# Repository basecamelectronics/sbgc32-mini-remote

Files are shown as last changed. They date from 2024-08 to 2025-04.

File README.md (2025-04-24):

Mini-Remote Controller Hardware
===============================
Web-site (https://www.basecamelectronics.com)

Description
-----------
This repository contains the main production files and other 3D files related to the MiniRemote project.

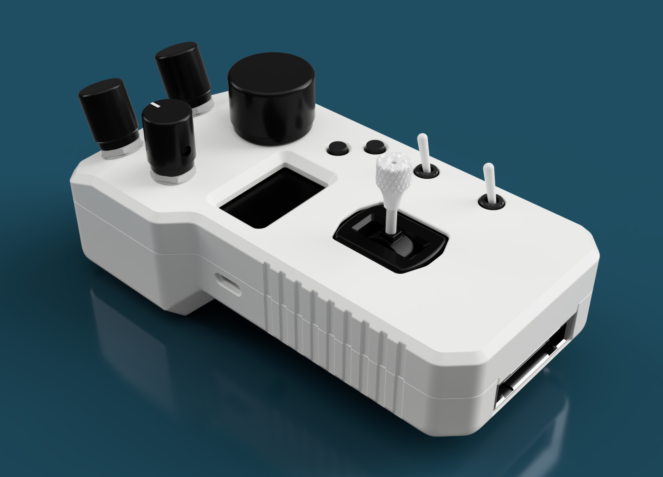
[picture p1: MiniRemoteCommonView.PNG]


The code for this device is also open-source. You can find it <a href="https://github.com/basecamelectronics/sbgc32-serial-api/tree/master/examples/STM32/MiniRemote">here</a></center>.
This folder contains a <a href="https://github.com/basecamelectronics/sbgc32-serial-api/tree/master/examples/STM32/MiniRemote/MiniRemoteDescription.pdf">document</a></center> with a more detailed description of the project.
This project will soon be available for order in our store.

Files Description
-----------------

[3D_Models/](3D_Models) - a folder with .step and .stl PCB 3D files;

[Enclosure/](Enclosure) - 3D models of the MiniRemote's casing and joysticks;

[PCB/](PCB) - the general manufacture files and sources;

[changelog.txt](changelog.txt) - a project changelog;

[MiniRemoteAccessories.csv](MiniRemoteAccessories.csv) - BOM for enclosure assembly;

[MiniRemoteAssemblyInstruction.pdf](MiniRemoteAssemblyInstruction.pdf) - Detailed assembly instructions.

Feedback
--------

If you have any questions or suggestions about using MiniRemote, you can contact at:

support@basecamelectronics.com

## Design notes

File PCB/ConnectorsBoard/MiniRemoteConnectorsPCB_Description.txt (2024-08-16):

MiniRemoteConnectorsPCB
=======================

Material: FR4
Dimension: 32x23mm
Layers: 2 (two)
PCB thickness: 1.6mm
Copper thickness: 35um
Solder mask: BLACK
Silkscreen: WHITE, top + bottom
Immersion gold plated

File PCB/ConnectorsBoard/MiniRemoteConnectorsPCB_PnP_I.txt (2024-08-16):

Altium Designer Pick and Place Locations
D:\basecam\MiniRemote\Project Outputs for MiniRemote\Pick Place\Generates pick and place files.txt

========================================================================================================================
File Design Information:

Date:       02.07.24
Time:       20:04
Revision:   Not in VersionControl
Variant:    No variations
Units used: mil

Designator Comment   Layer       Center-X(mil) Center-Y(mil) Rotation Description                                
P8         RS-422    TopLayer    976.772       598.032       180      "CONN RCPT FMALE 6POS GOLD SOLDER"         
P10        SerialAPI TopLayer    268.110       598.032       180      "CONN RCPT FMALE 4POS GOLD SOLDER"         
P7         LEMO_PCB  TopLayer    629.921       234.252       180      "WR-FPC 0.50 mm 10-pin SMT ZIF Horizontal" 
C31        100nF     BottomLayer 1010.000      375.002       0        "0603 100nF 50V X7R 10%"                   
C30        100nF     BottomLayer 614.998       450.000       90       "0603 100nF 50V X7R 10%"                   
C28        100nF     BottomLayer 399.998       583.032       90       "0603 100nF 50V X7R 10%"                   
C27        100nF     BottomLayer 539.998       450.000       90       "0603 100nF 50V X7R 10%"

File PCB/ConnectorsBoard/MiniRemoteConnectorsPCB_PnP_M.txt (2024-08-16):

Altium Designer Pick and Place Locations
D:\basecam\MiniRemote\Project Outputs for MiniRemote\Pick Place\Generates pick and place files.txt

========================================================================================================================
File Design Information:

Date:       02.07.24
Time:       20:05
Revision:   Not in VersionControl
Variant:    No variations
Units used: mm

Designator Comment   Layer       Center-X(mm) Center-Y(mm) Rotation Description                                
P8         RS-422    TopLayer    24.8100      15.1900      180      "CONN RCPT FMALE 6POS GOLD SOLDER"         
P10        SerialAPI TopLayer    6.8100       15.1900      180      "CONN RCPT FMALE 4POS GOLD SOLDER"         
P7         LEMO_PCB  TopLayer    16.0000      5.9500       180      "WR-FPC 0.50 mm 10-pin SMT ZIF Horizontal" 
C31        100nF     BottomLayer 25.6540      9.5251       0        "0603 100nF 50V X7R 10%"                   
C30        100nF     BottomLayer 15.6210      11.4300      90       "0603 100nF 50V X7R 10%"                   
C28        100nF     BottomLayer 10.1600      14.8090      90       "0603 100nF 50V X7R 10%"                   
C27        100nF     BottomLayer 13.7160      11.4300      90       "0603 100nF 50V X7R 10%"

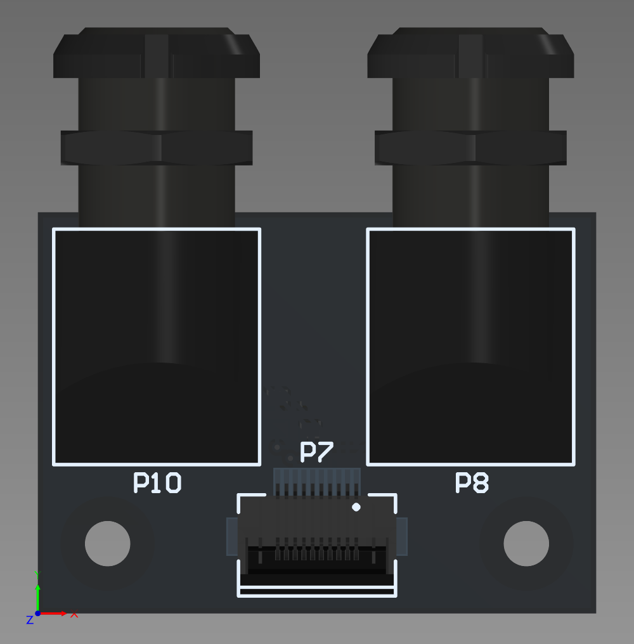
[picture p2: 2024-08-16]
PCB/ConnectorsBoard/MiniRemoteConnectorsMD_Top.png

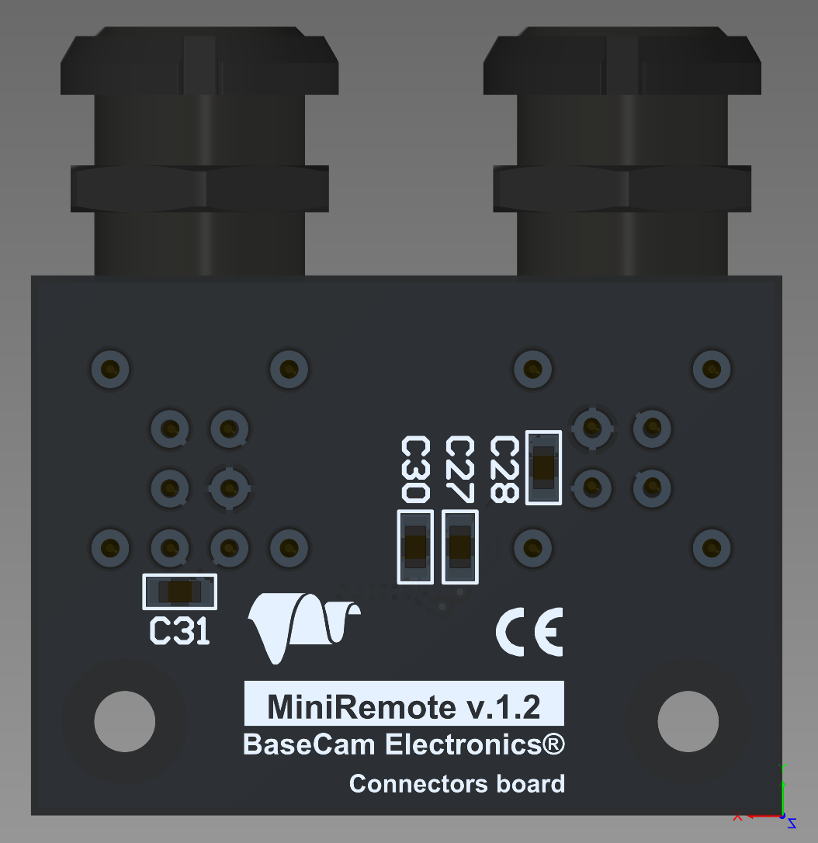
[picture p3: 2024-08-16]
PCB/ConnectorsBoard/MiniRemoteConnectorsMD_Bottom.png

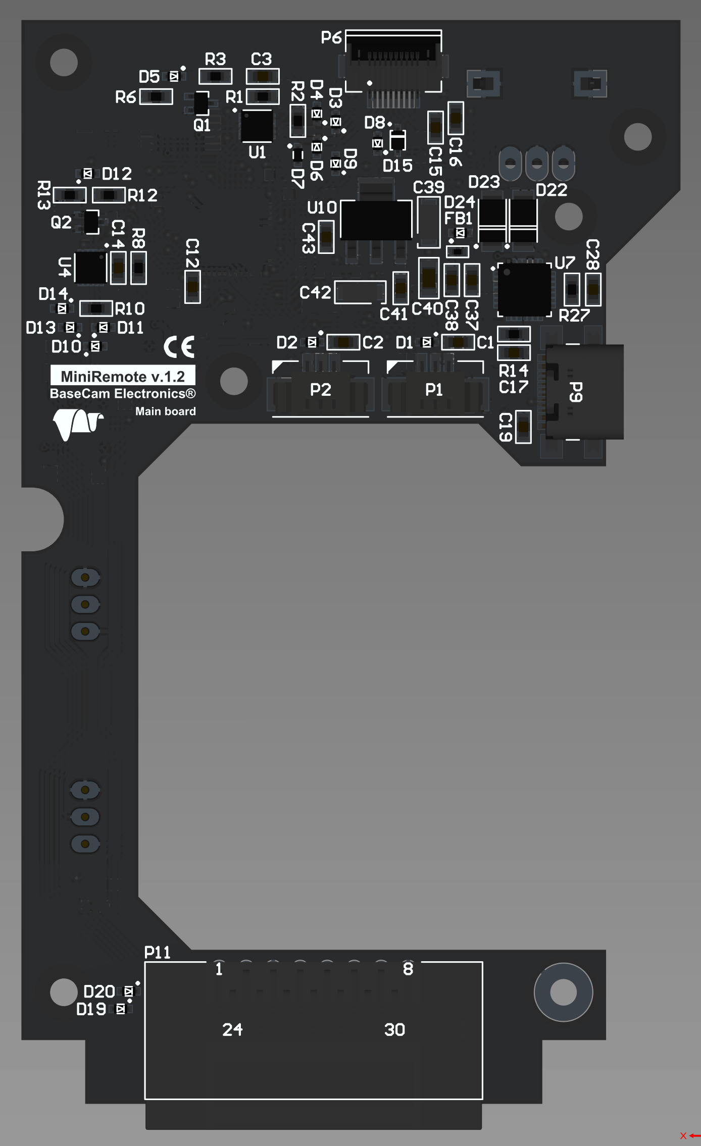
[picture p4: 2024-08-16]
PCB/MainBoard/MiniRemoteMainMD_Bottom.png

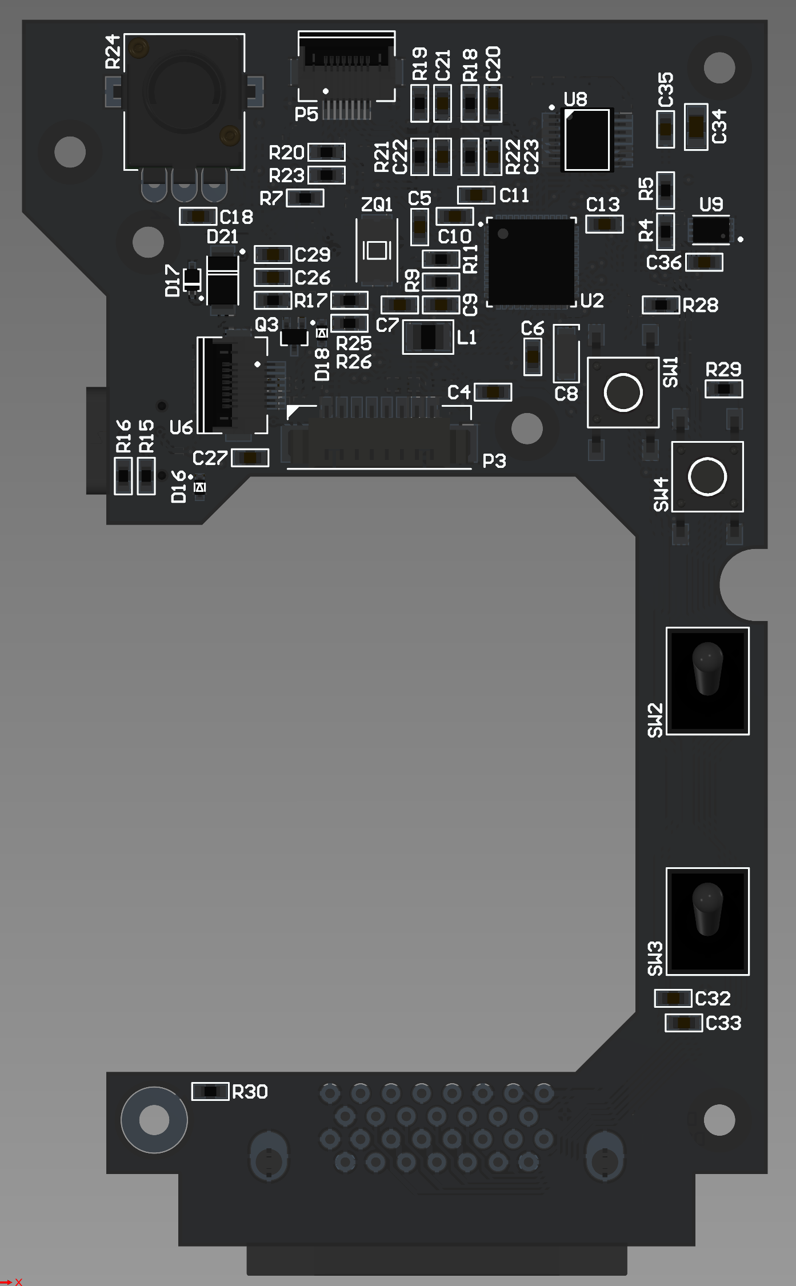
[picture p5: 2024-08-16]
PCB/MainBoard/MiniRemoteMainMD_Top.png

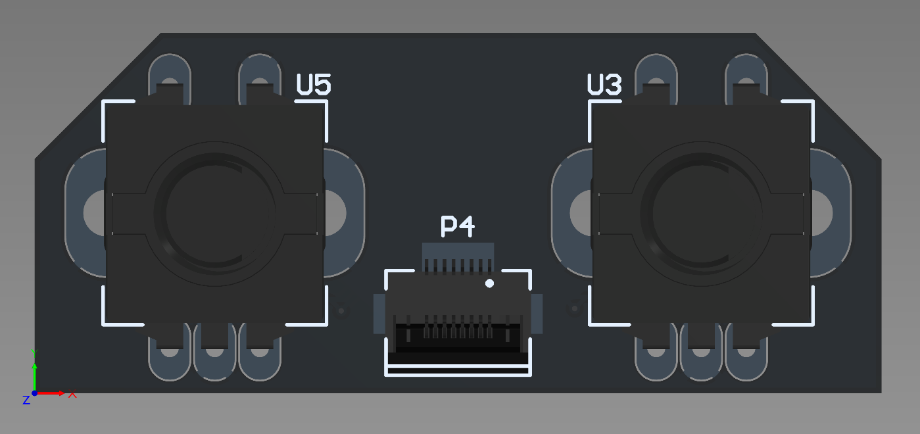
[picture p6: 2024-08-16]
PCB/EncodersBoard/MiniRemoteEncodersMD_Top.png

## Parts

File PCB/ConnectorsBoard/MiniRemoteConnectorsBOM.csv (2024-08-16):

Designator | Name | Value | Description | Quantity
C27, C28, C30, C31 |  | 100nF | 0603 100nF 50V X7R 10% | 4
P7 | 687110149022 |  | WR-FPC 0.50 mm 10-pin SMT ZIF Horizontal | 1
P8 | EXG.0B.306.HLN |  | CONN RCPT FMALE 6POS GOLD SOLDER | 1
P10 | EXG.0B.304.HLN |  | CONN RCPT FMALE 4POS GOLD SOLDER | 1

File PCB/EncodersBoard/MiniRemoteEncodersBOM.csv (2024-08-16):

Designator | Name | Value | Description | Quantity
P4 | 687108149022 |  | WR-FPC 0.50 mm 8-pin SMT ZIF Horizontal | 1
U3, U5 | PEC11L-4115F-S0020 |  | ROTARY ENCODER MECHANICAL 20PPR | 2

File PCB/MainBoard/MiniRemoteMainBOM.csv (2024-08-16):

Designator | Name | Value | Description | Quantity
C1, C2, C3, C4, C9, C10, C11, C12, C13, C14, C15, C16, C17, C19, C26, C27, C32, C33, C36, C38, C41, C43 |  | 100nF | 0603 100nF 50V X7R 10% | 22
C5, C7 |  | 8pF | 0603 8pF 50V C0G 5% | 2
C6, C29 |  | 2.2uF | 0603 2.2uF 10V X7R 10% | 2
C8 |  | 2.2uF | 1206 (A) 2.2uF 16V 10% | 1
C18, C20, C21, C22, C23, C28, C37 |  | 10nF | 0603 10nF 100V X7R 10% | 7
C34, C40 |  | 10uF | 0805 10uF 10V X5R 10% | 2
C35 |  | 1uF | 0603 1uF 10V X7R 10% | 1
C39 |  | 47uF | 1206 (A) 47uF 10V 20% | 1
C42 |  | 10uF | 1206 (A) 10uF 10V 10% | 1
D1, D2, D3, D4, D5, D6, D7, D10, D11, D12, D13, D14, D16, D18, D24 | ESD5B5.0ST1G |  | TVS DIODE 5VWM SOD523 | 15
D8, D9, D19, D20 | ESD3V3D5 |  | TVS DIODE 3.3VWM SOD523 | 4
D15, D17 | BAT760 |  | DIODE SCHOTTKY 20V 1A SOD323 | 2
D21, D22, D23 | PMEG3030BEP,115 |  | DIODE SCHOTTKY 30V 3A SOD128 | 3
FB1 | EPZ1005E221-1R2T |  | 0402 220 OHM 1LN | 1
L1 |  | 3.3uH | 1008 3.3uH 1.2A 100m OHM | 1
P1, P2 | 10114830-10103LF |  | CONN HEADER SMD R/A 3POS 1.25MM | 2
P3 | 0532610871 |  | CONN HEADER SMD R/A 8POS 1.25MM | 1
P5 | 687108149022 |  | WR-FPC 0.50 mm 8-pin SMT ZIF Horizontal | 1
P6 | 687110149022 |  | WR-FPC 0.50 mm 10-pin SMT ZIF Horizontal | 1
P9 | USB4110-GF-A |  | CONN RCP USB2.0 TYP C 24P SMD RA | 1
P11 | TX25-30P-LT-H1E |  | CONN PLUG 30POS R/A GOLD | 1
Q1, Q2 | BSS816NW |  | MOSFET N-CH 20V 1.4A SOT323-3 | 2
Q3 | NTS4101PT1G |  | MOSFET P-CH 20V 1.37A SC70-3 | 1
R1, R7, R8, R9, R18, R19, R20, R21, R22, R23, R28, R29 |  | 10K | 0603 10K OHM 0.1W 1% | 12
R2, R10 |  | 120 | 0603 120 OHM 0.1W 1% | 2
R3, R12, R26 |  | 510 | 0603 510 OHM 0.1W 1% | 3
R4, R5 |  | 2.4K | 0603 2.4K OHM 0.1W 1% | 2
R6, R13, R25 |  | 47K | 0603 47K OHM 0.1W 1% | 3
R11 |  | 1K | 0603 1K OHM 0.1W 1% | 1
R14 |  | 4.7K | 0603 4.7K OHM 0.1W 5% | 1
R15, R16 |  | 5.1K | 0603 5.1K OHM 0.1W 1% | 2
R17 |  | 180 | 0603 180 OHM 0.1W 1% | 1
R24 | P0915N-FC15BR100K | 100K | POT 100K OHM 0.05W 20% | 1
R27 |  | 1M | 0603 1M OHM 0.1W 1% | 1
R30 |  | 0 | 0603 0 OHM 0.1W | 1
SW1, SW4 | TL3301SPF260QG |  | SWITCH TACTILE SPST-NO 0.05A 12V | 2
SW2 | B13AP |  | SWITCH TOGGLE SPDT 0.4VA 28V | 1
SW3 | B18AP |  | SWITCH TOGGLE SPDT 0.4VA 28V | 1
U1, U4 | LTC2864HDD-1#PBF |  | 20Mbps and Slew Rate Limited 15kV RS485/RS422 Transceiver | 2
U2 | STM32F411CEU6 |  | IC MCU 32BIT 512KB FLSH 48UFQFPN | 1
U6 | 687108149022 |  | WR-FPC 0.50 mm 8-pin SMT ZIF Horizontal | 1
U7 | CP2102 |  | Single-Chip USB to UART Data Transfer | 1
U8 | AS5048B |  | Magnetic Rotary Encoder | 1
U9 | CAT24C256 |  | Two-Wire I2C Serial EEPROM | 1
U10 | LM1117MPX-3.3 |  | 800-mA, Low-Dropout Linear Regulator | 1
ZQ1 | NX5032GA | 8 MHz | CRYSTAL 8.0000MHZ 8PF SMD | 1

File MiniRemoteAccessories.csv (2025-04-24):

Name | Quantity | Link | ÿ
Knobs
OEJNI-90-4-7 - Abs.enc. | 1 | https://www.digikey.com/en/products/detail/kilo-international/OEJL-90-4-7/710686
OEJL-50-4-5 - Pot. | 1 | https://www.digikey.com/en/products/detail/kilo-international/OEJL-50-4-5/710642
OEJNI-50-4-7 - Encs. | 2 | https://www.digikey.com/en/products/detail/kilo-international/OEJL-50-4-7/710650
1RBLK - Buttons | 2 | https://www.digikey.com/en/products/detail/e-switch/1RBLK/271579
Cables
FFC 10-pin 0.5mm L30mm B-dir | 1 | https://www.aliexpress.com/item/1005004583056284.html
FFC 8-pin 0.5mm L30mm A-dir | 1 | https://www.aliexpress.com/item/1005004583043404.html
FGG.0B.306 + cable 3m | 1 | https://www.aliexpress.com/item/32716755431.html
FGG.0B.304 + cable 1m | 1 | https://www.aliexpress.com/item/32716755431.html
Assembly encoder
Bearing M6x12x4 | 1 | https://www.aliexpress.com/item/1005004692070656.html
Oil seal M6x12x3 | 1 | https://www.aliexpress.com/item/1005002594687400.html
Pillow M6x22 | 1 | https://www.aliexpress.com/item/1005006371763253.html
Nylon washer M6x12x0.5 | 2 | https://www.aliexpress.com/item/1005005893035927.html
Magnet M6x3 | 1 | https://www.aliexpress.com/item/1005002848356452.html
3D Body Pillow Joint | 1
Assembly display
3D Body Display Stand | 1
LCD TFT 135x240 1.14 inch | 1 | https://www.aliexpress.com/item/1005003772191934.html
Brass pillow M2.5x4 | 2 | https://www.aliexpress.com/item/1005002952338852.html
Screws PH1 M2.5x6 | 2
Nuts M2.5 | 2
Assembly case
3D Body Top | 1
3D Body Bottom | 1
Screws PH1 M2.5x16 - Top-Bottom | 6
Screws PH1 M2.5x6 - PCB-Bottom | 4
Screws PH1 M2x4 - Joystick-Top | 4
M12 Light Joystick | 1 | https://www.aliexpress.com/item/4001243553801.html

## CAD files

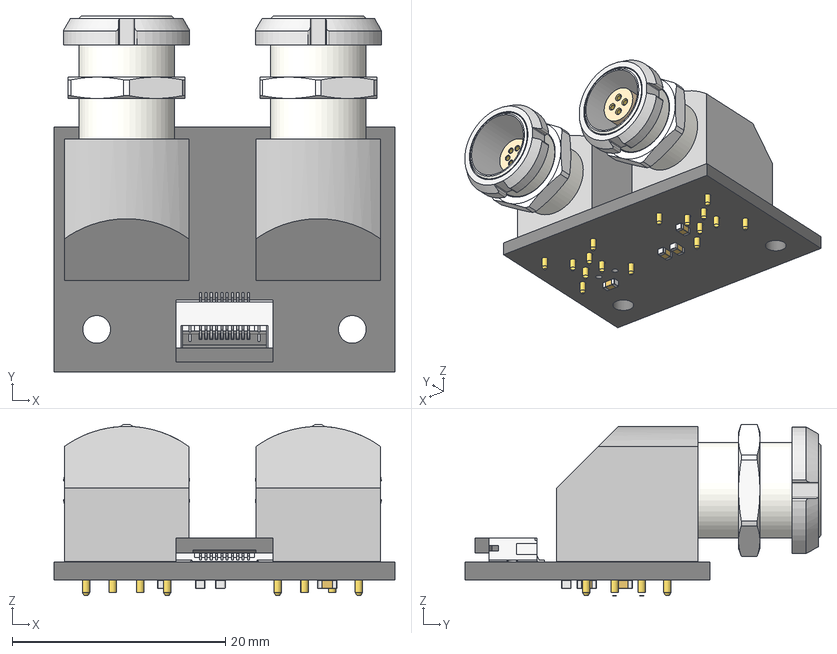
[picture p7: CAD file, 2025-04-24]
3D_Models/MiniRemoteConnectorsPCB.step
32.0 x 33.4 x 16.1 mm
EXG_0B_306_HLN
EXG_0B_304_HLN
6871xx149022_Pin x 10
6871xx149022_Patte
6871xx149022_Patte2
687110149022_Actuator

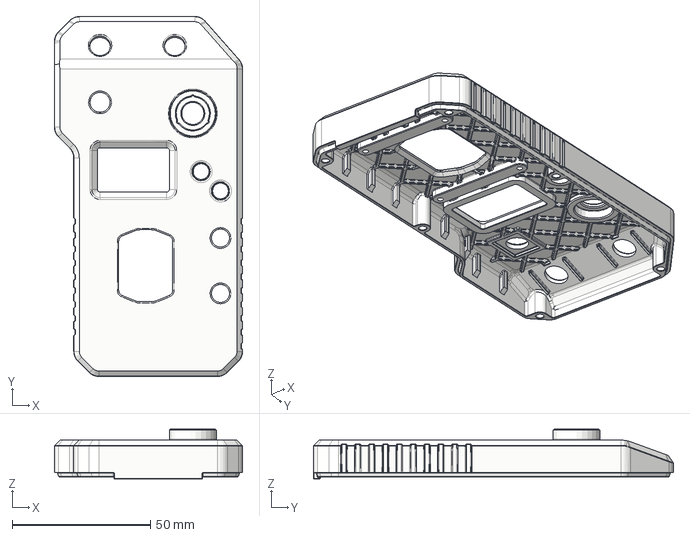
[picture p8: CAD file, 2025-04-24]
Enclosure/MiniRemoteBodyTop.step
68.0 x 130.0 x 18.0 mm

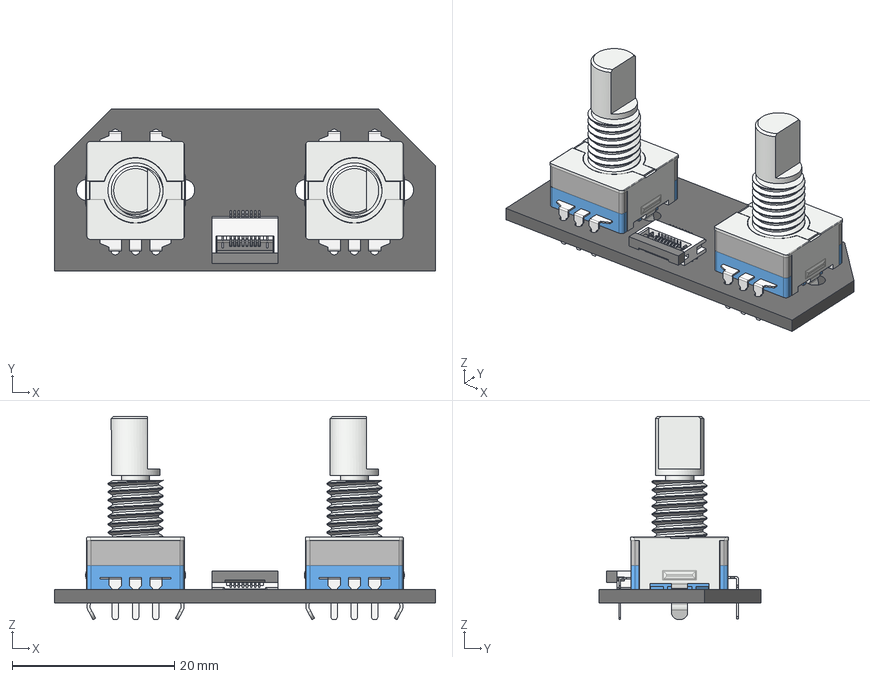
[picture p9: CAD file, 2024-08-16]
3D_Models/MiniRemoteEncodersPCB.step
47.0 x 20.0 x 25.1 mm
EC11-THT-Shaft_15MM_Blue x 2
6871xx149022_Pin x 8
6871xx149022_Patte
6871xx149022_Patte2
687108149022_Actuator

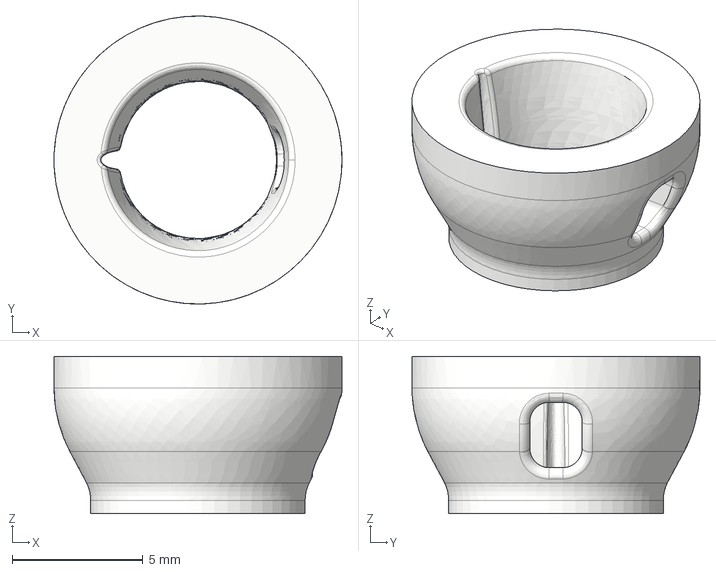
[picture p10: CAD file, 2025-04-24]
Enclosure/MiniRemoteEncoderPillowJoint.step
11.0 x 11.0 x 6.00 mm

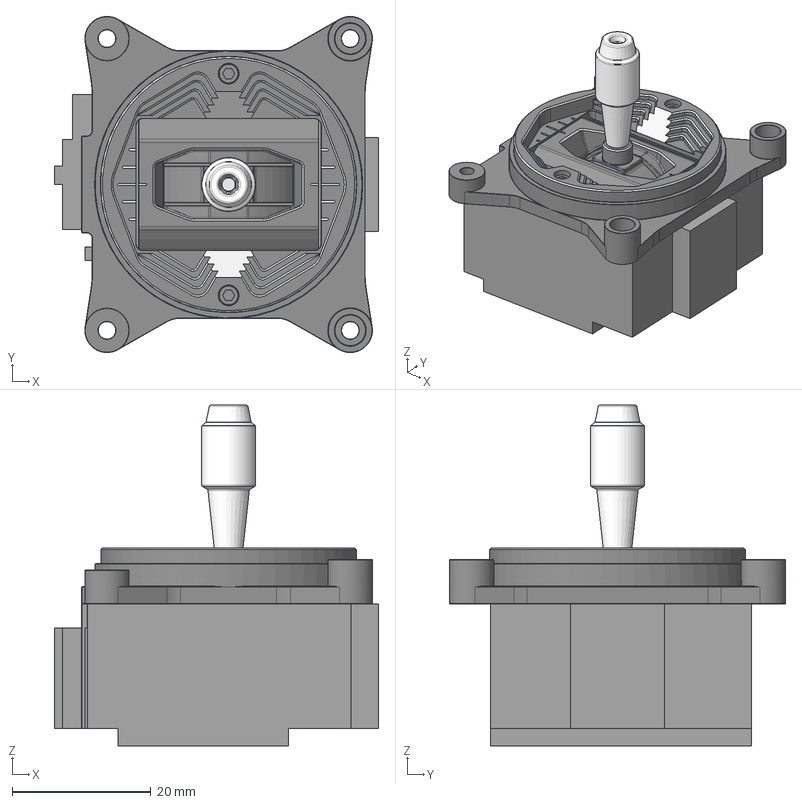
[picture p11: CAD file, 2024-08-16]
Enclosure/AG01 MINI CNC Hall Gimbals for TX12 & Zorro.step
46.8 x 48.5 x 49.2 mm

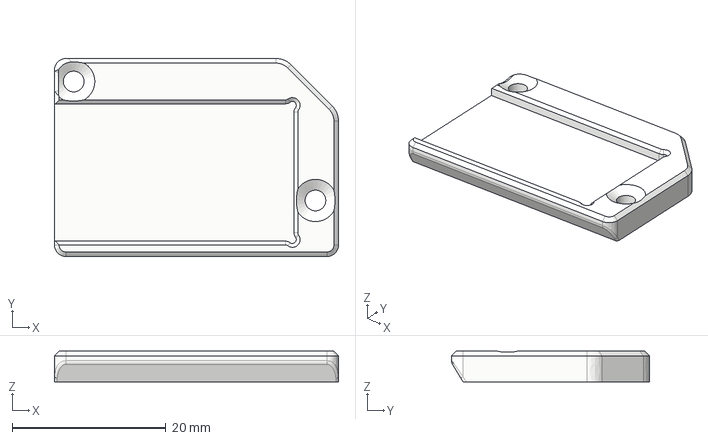
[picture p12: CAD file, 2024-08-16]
Enclosure/MiniRemoteDisplayStand.step
37.0 x 25.8 x 4.00 mm

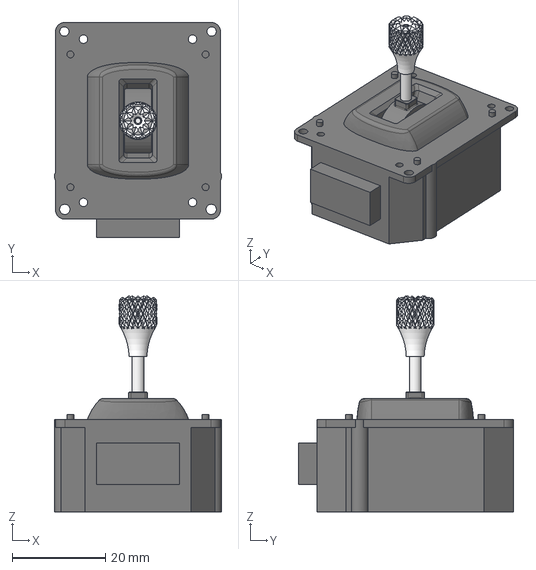
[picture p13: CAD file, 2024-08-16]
Enclosure/X-LiteProStick.step
35.8 x 46.2 x 46.3 mm

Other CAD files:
3D_Models/MiniRemoteConnectorsPCB.stl
3D_Models/MiniRemoteEncodersPCB.stl
Enclosure/MiniRemoteBodyTop.stl
Enclosure/MiniRemoteDisplayStand.stl

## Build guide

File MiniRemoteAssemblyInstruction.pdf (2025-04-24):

# MiniRemote assembly instruction

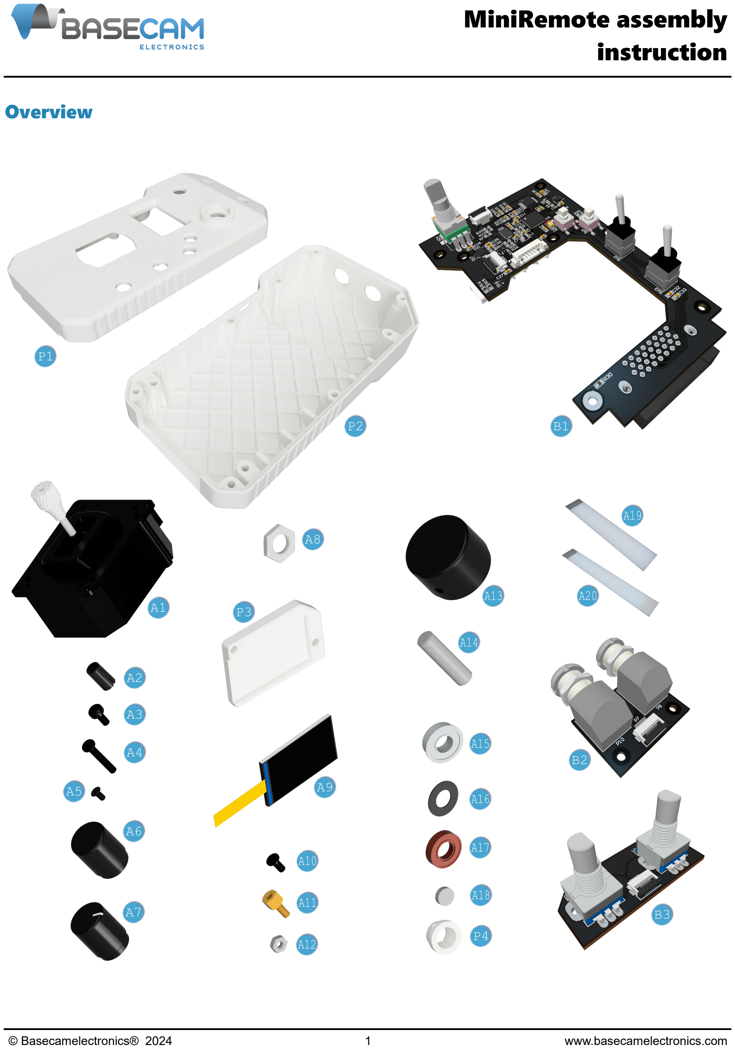
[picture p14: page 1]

## Overview

© Basecamelectronics® 2024 | 1 | www.basecamelectronics.com

# instruction

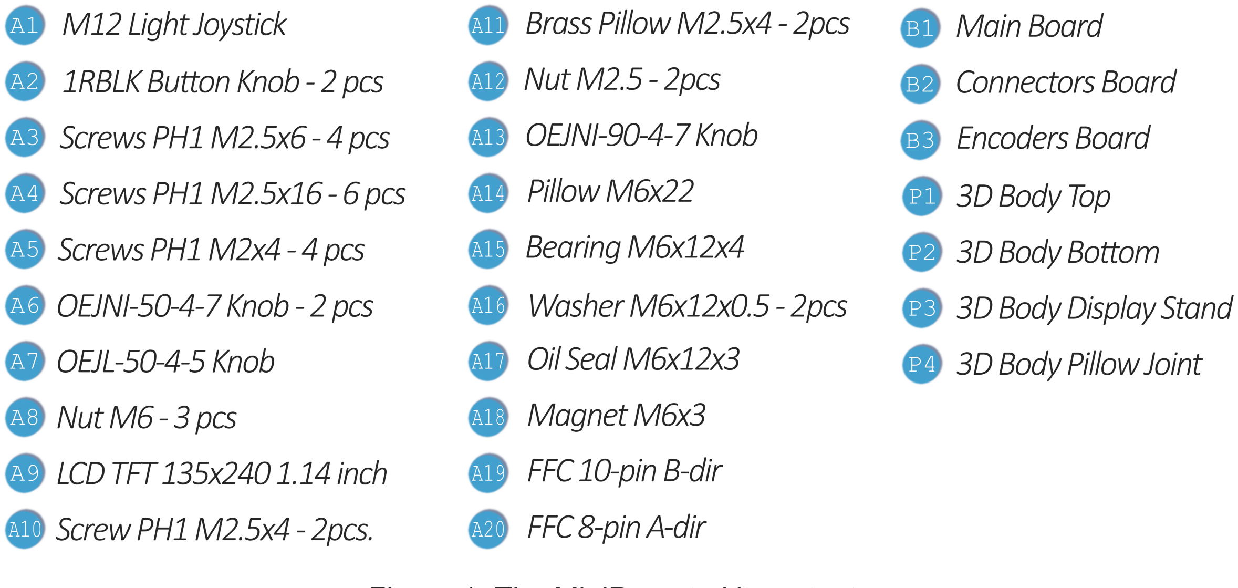
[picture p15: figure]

Figure 1. The MiniRemote kit contents

Notes:
- The encoder magnet must not be heated. Exposure to high temperatures causes it to lose its magnetic properties;
- When installing FFC cables into connectors, you can use an auxiliary tool, such as a plastic hand tool. Do not use sharp metal objects for this purpose;
- If the joystick is installed upside down, you can invert the axis back using software mixers (Remote → Mixer Settings);
- When threading plastic with a screw, it may feel quite tight the first time. During subsequent assembly/disassembly, the screw rotation will become much smoother;
- The nuts A8 are included in the set and are attached to their corresponding radio components. Remove them before step 8.
© Basecamelectronics® 2024 | 2 | www.basecamelectronics.com

# instruction

## Assembly order

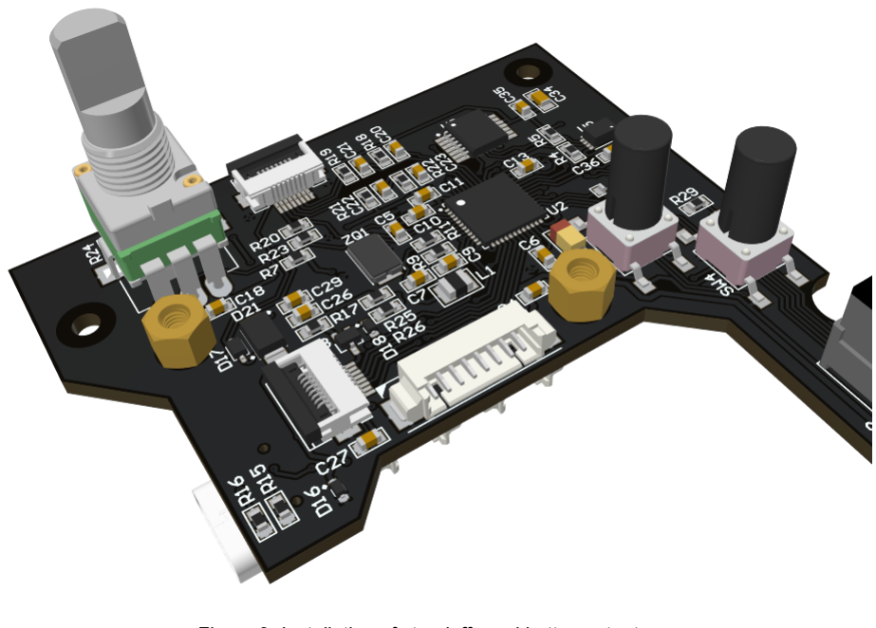
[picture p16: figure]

Figure 2. Installation of standoffs and button actuators

1. To prepare the motherboard, first install two standoffs for the display using M2.5 nuts A12 and M2.5x4 brass pillows A11. Installing washers is optional and serves only to preserve the solder mask layer on the board. Avoid overtightening the nuts to prevent damage to the motherboard. Then, attach the 1RBLK actuators A2 to the SW1 and SW4 buttons.
© Basecamelectronics® 2024 | 3 | www.basecamelectronics.com

# instruction

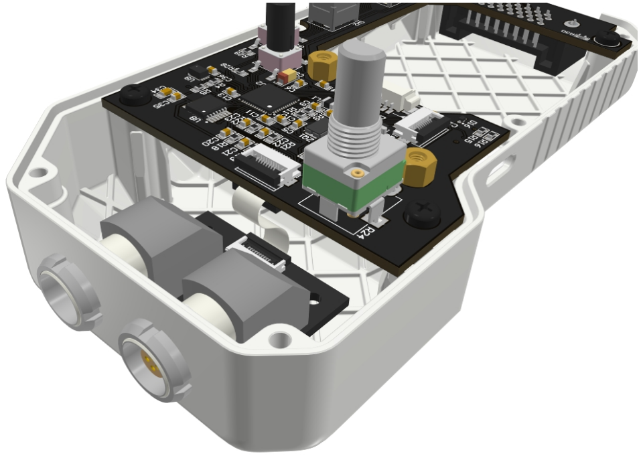
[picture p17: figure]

Figure 3. Installation of the board with connectors

2. First, remove the front locking nuts from the connectors. The connection is made using a 10-pin 0.5mm FFC cable, 30mm in length A19. The corresponding connector on the main board is located on its underside. Secure both ends of the cable tightly into the connectors on these boards. Next, take the bottom part of the remote control case P2 and install the assembly of interconnected boards into it. Loosen the rear nuts on the LEMO connectors to about halfway along their thread length. It is recommended to start by installing this section into the front part of the remote control case. Then, place the main board onto the supports located on the side walls of the case. Ensure that all four mounting holes and the side USB Type-C connector are properly aligned. Finally, secure the board with the LEMO connectors using the previously removed external nuts, and attach the main board with four M2.5x6 screws A3.
© Basecamelectronics® 2024 | 4 | www.basecamelectronics.com

# instruction

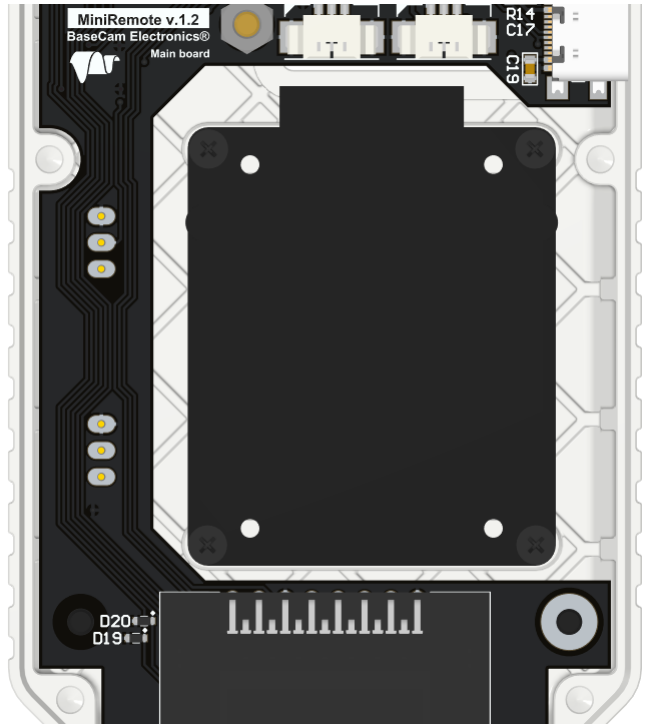
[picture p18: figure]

Figure 4. Joystick installation

3. Take the top part of the MiniRemote case P1 and secure the joystick A1 using four M2x4 self-tapping screws A5. It is recommended to install the joystick so that the Hall sensor of the X-axis (ROLL) faces the back of the MiniRemote. Avoid overtightening the screws. Then insert the joystick plug into the corresponding connector on the top of the motherboard, next to the joystick.
© Basecamelectronics® 2024 | 5 | www.basecamelectronics.com

# instruction

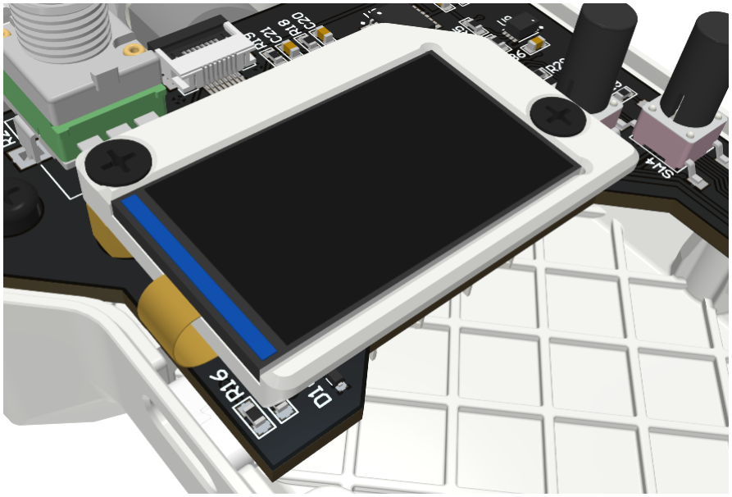
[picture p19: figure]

Figure 5. Display installation

4. First, insert the display A9 into the FPC connector as shown in the diagram above. Then position the display frame P3 on the previously secured brass pillows and and secure with screws A10. Place the display itself inside this frame. Optionally, you can use thin double-sided tape or super glue for additional fixation. Carefully bend the display flex cable inward so that it does not extend beyond the boundaries of the remote control case.
© Basecamelectronics® 2024 | 6 | www.basecamelectronics.com

# instruction

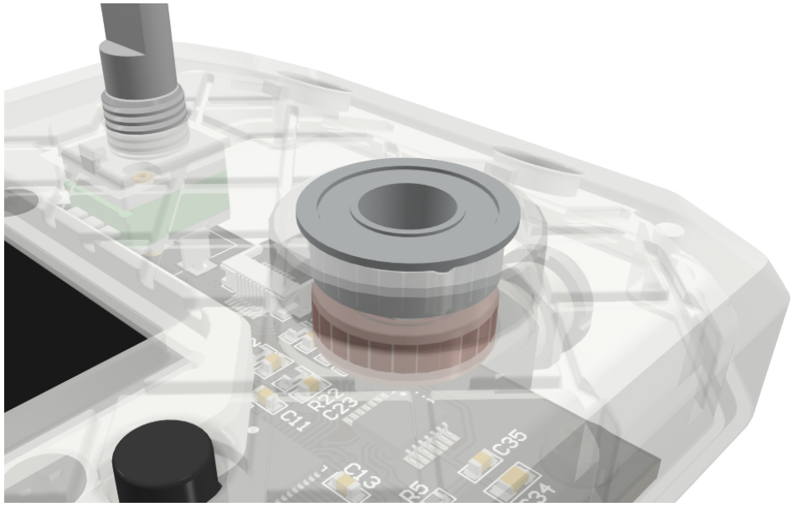
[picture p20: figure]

Figure 6. Encoder knob installation, part 1

5. Secure the encoder's seal A17 and bearing A15 in the designated holes, as shown in the diagram above. They will hold firmly in place, but optionally, you can add a small amount of super glue during installation for extra security.
© Basecamelectronics® 2024 | 7 | www.basecamelectronics.com

# instruction

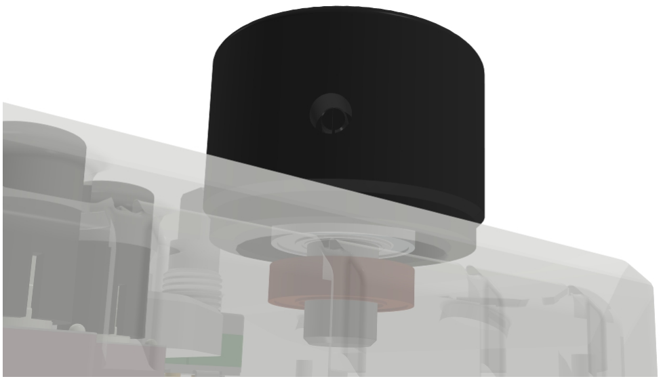
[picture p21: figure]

Figure 7. Encoder knob installation, part 2

6. Now, prepare the encoder knob A13 for installation. Attach the knob to the shaft A14 using the side screw. Then, from the bottom side, place a thin nylon washer M6x12x0.5 A16 onto the shaft. Lubricate the shaft evenly around its circumference. It can now be inserted through the bearing and seal into the case.
© Basecamelectronics® 2024 | 8 | www.basecamelectronics.com

# instruction

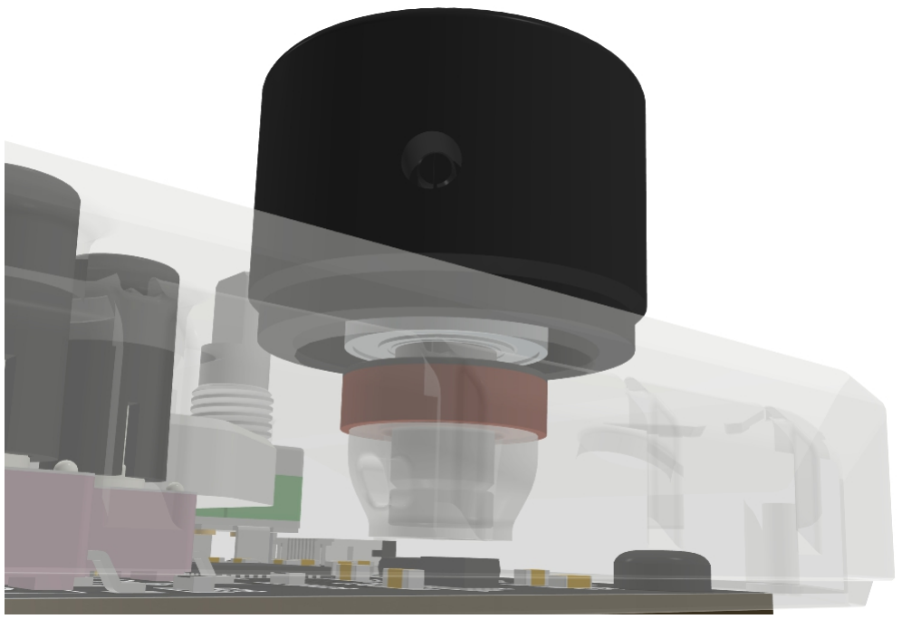
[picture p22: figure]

Figure 8. Encoder knob installation, part 3

7. Slide a nylon washer M6x12x0.5 A16 onto the shaft. Insert an M6x3 magnet A18 into the Pillow Joint component P4. Then press this component onto the shaft from above, as shown in the picture above.
© Basecamelectronics® 2024 | 9 | www.basecamelectronics.com

# instruction

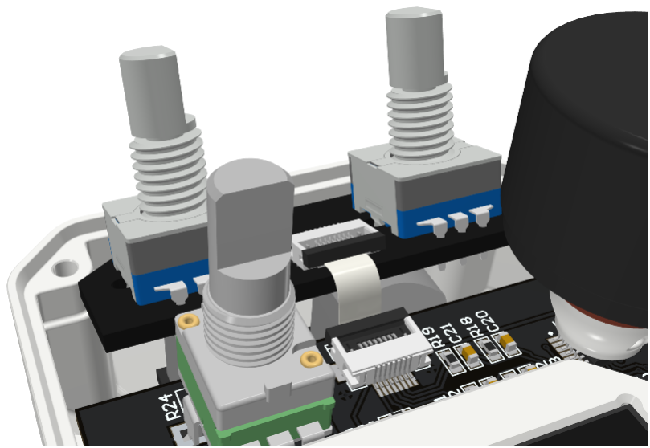
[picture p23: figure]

Figure 9. Encoders board installation

8. The final internal component is the encoder board B3. It needs to be connected to the motherboard using an FFC cable A20. Now you can join the top and bottom halves of the remote control. While doing this, try to support the encoder board from underneath first, and then from above.
© Basecamelectronics® 2024 | 10 | www.basecamelectronics.com

# instruction

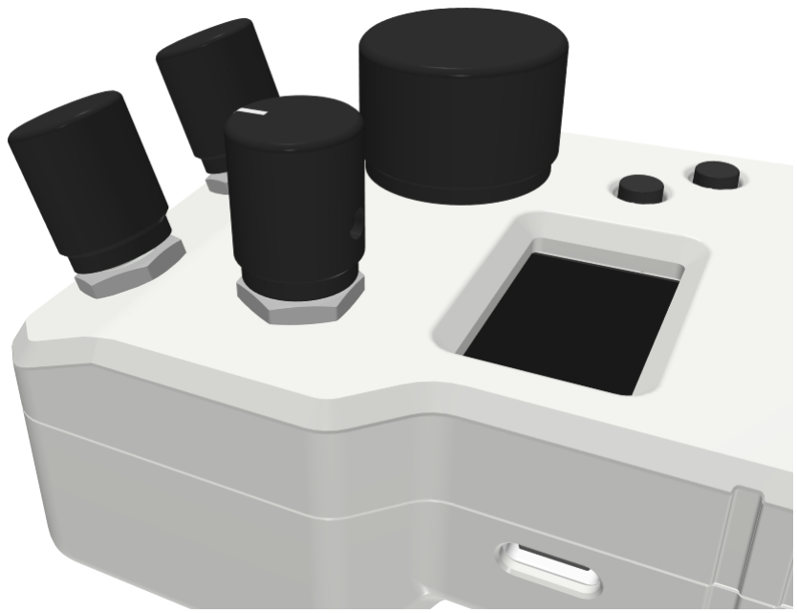
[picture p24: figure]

Figure 10. Knobs installation

9. Now secure the encoders and the variable resistor to the case using M6 nuts A8. Then attach the knobs OEJL-50-4-5 A7 and OEJNI-50-4-7 A6 (the one with the white mark goes on the resistor). Fix them in place using the side screw. Ensure they are positioned at a height from the case surface such that the encoder buttons can be pressed freely and the variable resistor knob does not rub against the plastic when rotated.
© Basecamelectronics® 2024 | 11 | www.basecamelectronics.com

# instruction

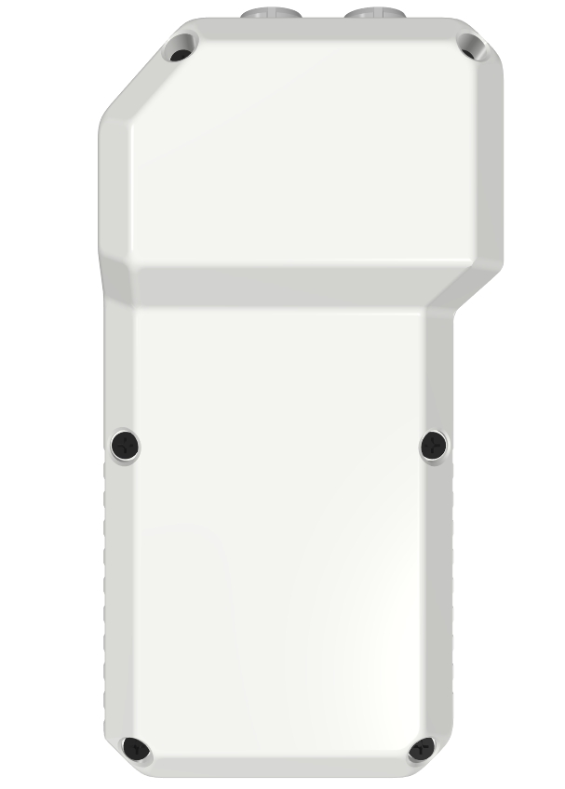
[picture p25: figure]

Figure 11. Securing the top and bottom parts of the case

10. Flip the remote control over and secure the two halves of the case with six screws A4. The device is now fully assembled and ready for use.
© Basecamelectronics® 2024 | 12 | www.basecamelectronics.com

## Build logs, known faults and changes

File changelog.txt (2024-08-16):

‾‾‾‾‾‾‾‾‾‾‾‾‾‾‾‾‾‾‾‾‾‾‾‾‾‾‾‾‾‾‾‾‾‾‾‾‾‾‾‾‾‾‾‾‾‾‾‾‾‾‾‾‾‾‾‾‾‾‾‾‾‾‾‾‾‾‾‾‾‾‾‾
                                Releases
________________________________________________________________________

### Release 1.2  - - - - - - - - - - - - - - - - - - - - - - - - - - - -

Schematic:
- Fixed analog joystick connectors' pinout;
- Added bypass capacitors for the RS-422 chips;
- The limitation of copper layers for mounting holes is done using rules, without keep-out layer;
- Minor optimization in the layout and routing of the Main PCB.

Frame:
- The display frame is lowered 1 mm down until it makes tight contact with its mounts.

### Release 1.1  - - - - - - - - - - - - - - - - - - - - - - - - - - - -

Schematic:
- The operation of USART1 has been slightly changed, a Schottky diode has been added to the Tx pin on the SBGC32 side, a pull-up resistor has been added;
- The gates of all MOSFETs are protected by 5V TVS diodes;
- For RS-422 converters, the terminator resistor has moved to pins A and B;
- The logic for adjusting the display brightness on a P-channel transistor has changed;
- All the capacitors previously necessary for anti-bouncing contacts have disappeared. Now this task is handled by the firmware. The capacitors on the encoders changed from 100nF to 10nF. The button logic has been inverted;
- The bootloader works without a transistor, directly from SW1;
- Fixed a bug with the order of pins on the connector for a board with LEMO connectors;
- The FPC display connector has moved to the right to give more space for the cable, the joystick connectors (from the edge) and USB connectors (towards the edge) have moved slightly;
- Fixed non-working footprint for the CP2102 chip;
- The footprint of the encoders has changed slightly for more accurate positioning;
- The space for the joystick on the side of the shield connector has increased slightly.

Frame:
- The top side was made 0.5mm thinner;
- The display frame is slightly smaller;
- The mount for the absolute encoder handle has been redesigned;
- The holes for LEMO connectors have changed to 9mm;
- The cutout for USB-TypeC has changed slightly;
- The shape of the display support has changed.

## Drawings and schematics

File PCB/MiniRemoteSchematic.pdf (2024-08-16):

RS-422 CONVERTER LEMO | CONNECTORS

# MCU

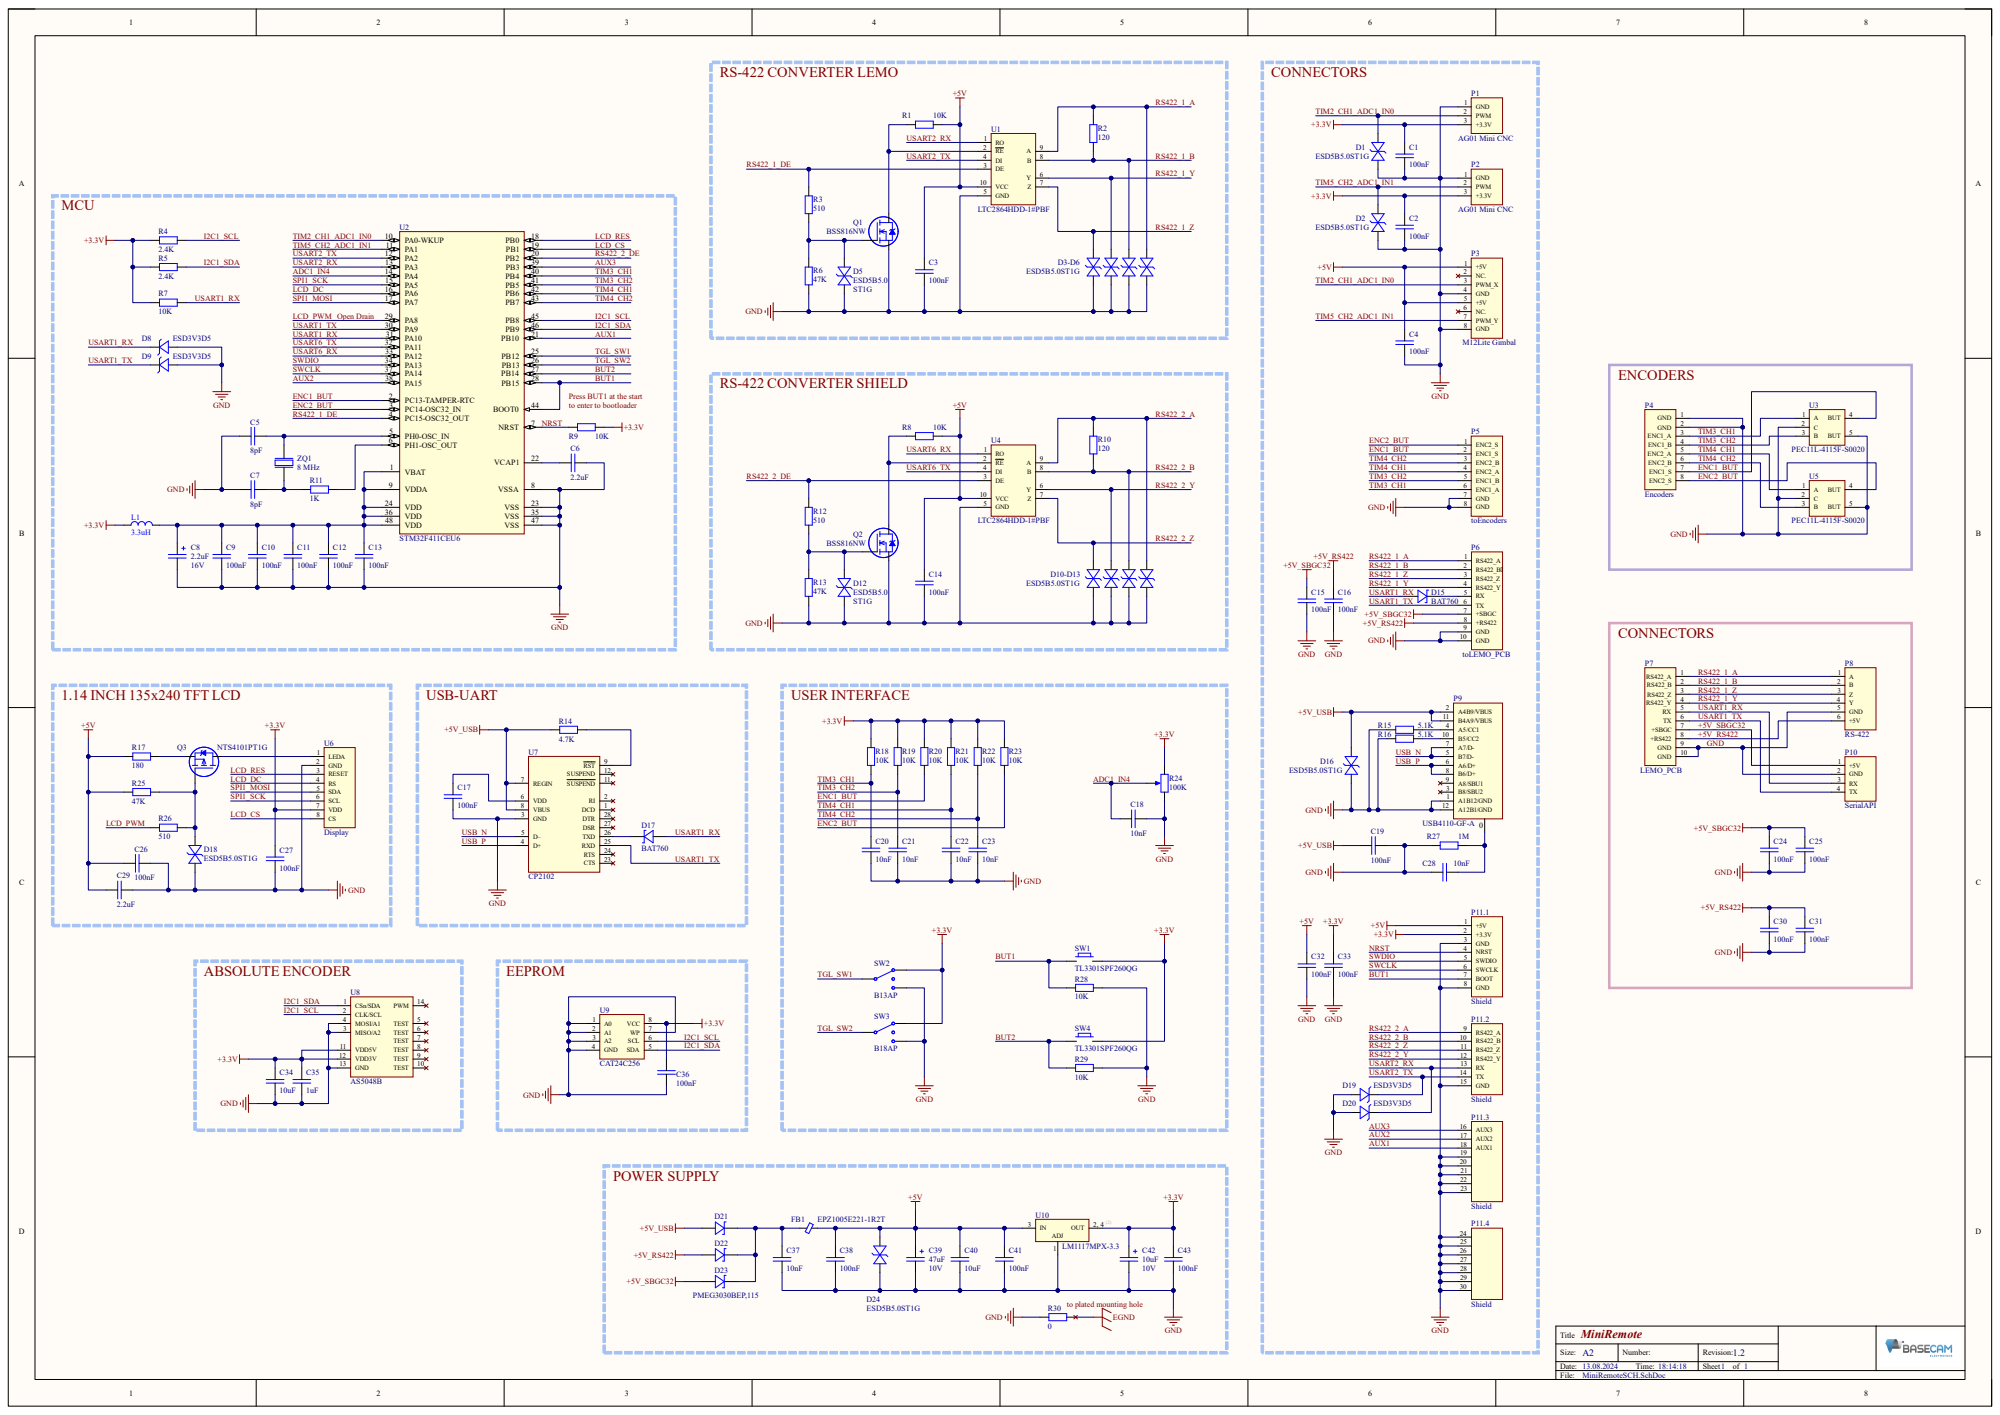
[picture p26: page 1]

Press BUT1 at the start
to enter to bootloader

to plated mounting hole

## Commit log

2024-08-16 v1.2 Release
    [AG01 MINI CNC Hall Gimbals for TX12 & Zorro.step, MiniRemoteAccessories.csv, MiniRemoteConnectorsBOM.csv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]
2025-04-24 v1.2 - minor files changes
    [MiniRemoteAccessories.csv, MiniRemoteBodyTop.step, MiniRemoteBodyTop.stl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]
